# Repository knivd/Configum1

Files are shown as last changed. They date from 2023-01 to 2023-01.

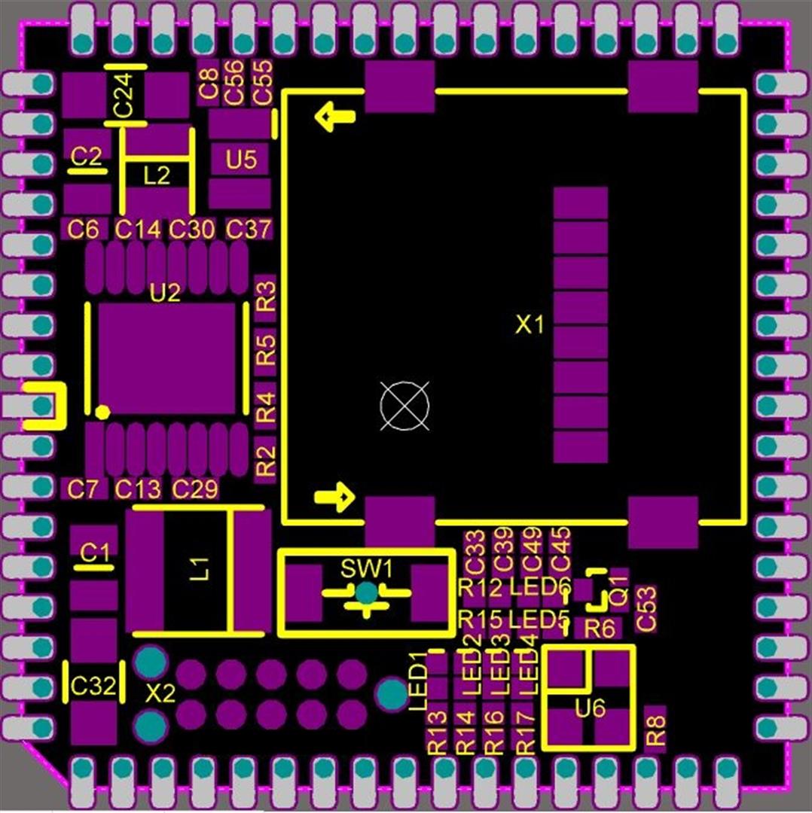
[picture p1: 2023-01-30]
manufacturing/Assembly-TOP.JPG

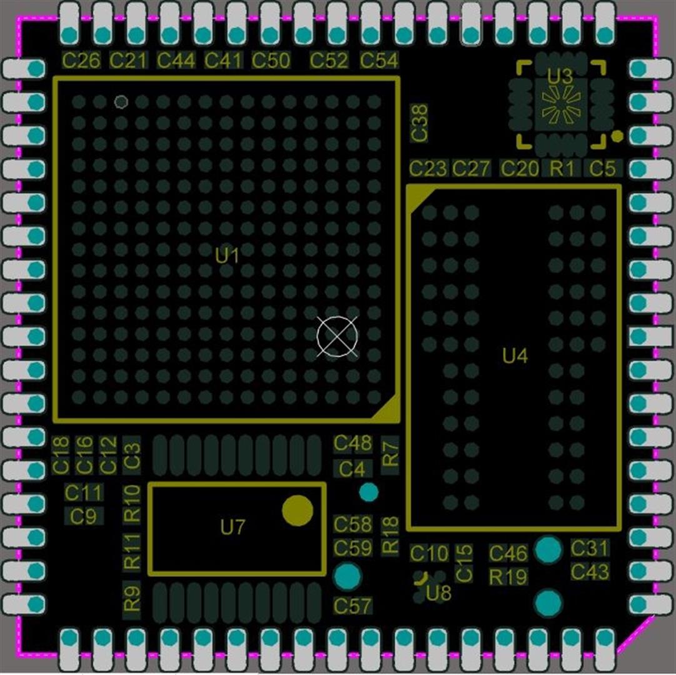
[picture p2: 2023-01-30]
manufacturing/Assembly-BOTTOM.JPG

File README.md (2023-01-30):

# Configum1
Embedded FPGA module in PLCC68 format

This tiny module has Spartan-6 FPGA, full power for it (works from any power outside in the range 3.3...20V, and even generates 3.3V for external user circuits), configuration memory, 64Mbytes DDR, microSD holder, 24MHz clock oscillator, JTAG pads, reset button, 8-bit configurable universal ADC/DAC/IO port, and even four on-board user-controllable LEDs.

And this whole this is... only 25x25mm big and fits into a standard PLCC-68 socket.

Applications - everything from industrial control to soft-core modular computers.

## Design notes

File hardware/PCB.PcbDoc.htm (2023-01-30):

Reporting Options

# File in Previous Format

Date | : | 23/02/2017
Time | : | 21:50:20
Filename | : | K:\Work\Orphidia\Projects\Others\Configum\hardware\PCB.PcbDoc

Version | Warning

This file was generated by an earlier version of the software

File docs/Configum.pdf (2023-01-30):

# CONFIGUM

24950C

# Embedded FPGA Module

## DTX bus compatible

# DATA SHEET

## 1. Overview

### Feature Highlights

68-pin device in standard PLCC68 package; three possible ways of PCB mounting
DTX bus pin-compatible (3.3V logic levels)
Wide range input 5-20V DC power supply with capability of provision to external circuit Fully self-contained – does not need any external components to run
Xilinx Spartan-6® FPGA with 14579 logic cells (CSG225 package)
Xilinx configuration memory with JTAG support
64 Megabytes DDR memory
micro-SD card connector on board
24MHz crystal oscillator
Four built-in controllable LEDs
Up to 45 FPGA I/O lines plus 8-bit dedicated ADC/DAC/IO front-end Tag-Connect®

pads and reset button
RoHS compliant

### Typical Applications

- Soft-core computing
- Robotics
- High-speed data processing
- Hobby and academic projects
24950C | 1 / 6

## 2. Pinout

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
┌─┴─┴─┴─┴─┴─┴─┴─┴─┸─┴─┴─┴─┴─┴─┴─┴─┴─┐
│ 9 │ 7 │ 5 │ 3 │ ▲ 68│ 66│ 64│ 6261│
+VBAT ┤10 8 | 6 | 4 | 2 1 | 67 65 63 60├ F0
GND ┤11 | | | | 59├ F1
+3V3OUT ┤12 | | | | 58├ F2
nRESET ┤13 | | | | 57├ F3
F44 ┤14 | | | | 56├ F4
F43 ┤15 | | | | 55├ F5
F42 ┤16 | | | | 54├ F6
F41 ┤17 | | | | 53├ F7
F40 ┤18 | | | | 52├ F8
F39 ┤19 | | | | 51├ F9
F38 ┤20 | | | | 50├ F10
F37 ┤21 | | | | 49├ F11
F36 ┤22 | | | | 48├ F12
F35 ┤23 | | | | 47├ F13
F34 ┤24 | | | | 46├ F14
F33 ┤25 | | | | 45├ F15
F32 ┤26 28 30 32 34 36 38 40 4244├ F16 │ 27│ 29│ 31│ 33│ 35│ 37│ 39│ 41│ 43│ └─┬─┬─┬─┬─┬─┬─┬─┬─┬─┬─┬─┬─┬─┬─┬─┬─┬─┘

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
### Pinout Summary

Pin | Name | Type | Description
1 | GND | P | Ground
2 | TMS | I | JTAG TMS line
3 | TCK | I | JTAG TCK line
4 | TDO | O | JTAG TDO line
5 | TDI | I | JTAG TDI line
6 | INIT | I | FPGA INIT input; delays initialisation
7 | GND | P | Ground
8 | +VBAT | P | Positive power lead

9 | PWRON | I | Power enabling input (can be connected directly to +VBAT); active high
10 | +VBAT | P | Positive power lead
11 | GND | P | Ground
12 | +3V3OUT | P | +3.3V output from the internal regulator; can be used to supply power to external components and circuits
13 | nRESET | I | RESET line; internally biased to +3.3V
14 | F44 | I,O | FPGA pin B15
15 | F43 | I,O | FPGA pin H12
16 | F42 | I,O | FPGA pin F11
17 | F41 | I,O | FPGA pin G12
18 | F40 | I,O | FPGA pin F12
19 | F39 | I,O | FPGA pin G13
20 | F38 | I,O | FPGA pin F13
21 | F37 | I,O | FPGA pin H13
22 | F36 | I,O | FPGA pin G14
23 | F35 | I,O | FPGA pin E14
24 | F34 | I,O | FPGA pin B14
25 | F33 | I,O | FPGA pin C14
26 | F32 | I,O | FPGA pin H15
27 | FX | I,O | FPGA pin J14
28 | GND | P | Ground
29 | F31 | I,O | FPGA pin J13
30 | F30 | I,O | FPGA pin K13
31 | F29 | I,O | FPGA pin K12
32 | F28 | I,O | FPGA pin D15
33 | F27 | I,O | FPGA pin E15
34 | F26 | I,O | FPGA pin G15
35 | F25 | I,O | FPGA pin J15
36 | F24 | I,O | FPGA pin K15
37 | F23 | I,O | FPGA pin L14
38 | F22 | I,O | FPGA pin L15
39 | F21 | I,O | FPGA pin L12
40 | F20 | I,O | FPGA pin M15
41 | F19 | I,O | FPGA pin M13
42 | F18 | I,O | FPGA pin N15
43 | F17 | I,O | FPGA pin N14
44 | F16 | I,O | FPGA pin P15

45 | F15 | I,O | FPGA pin P14
46 | F14 | I,O | FPGA pin K11
47 | F13 | I,O | FPGA pin J11
48 | F12 | I,O | FPGA pin G11
49 | F11 | I,O | FPGA pin R11
50 | F10 | I,O | FPGA pin R10
51 | F9 | I,O | FPGA pin R9
52 | F8 | I,O | FPGA pin R8
53 | F7 | I,O | FPGA pin R6
54 | F6 | I,O | FPGA pin R5
55 | F5 | I,O | FPGA pin R4
56 | F4 | I,O | FPGA pin R13
57 | F3 | I,O | FPGA pin P13
58 | F2 | I,O | FPGA pin R7
59 | F1 | I,O | FPGA pin N11
60 | F0 | I,O | FPGA pin M11
61 | P0 | I,O,AI,AO | Universal front-end line 0
62 | P1 | I,O,AI,AO | Universal front-end line 1
63 | P2 | I,O,AI,AO | Universal front-end line 2
64 | P3 | I,O,AI,AO | Universal front-end line 3
65 | P4 | I,O,AI,AO | Universal front-end line 4
66 | P5 | I,O,AI,AO | Universal front-end line 5
67 | P6 | I,O,AI,AO | Universal front-end line 6
68 | P7 | I,O,AI,AO | Universal front-end line 7

Legend:
I – input with CMOS level | O – digital output | P – power pin
AI – analogue input | AO – analogue output

## 3. Electrical Parameters

ABSOLUTE MAXIMUM RATINGS:
Stresses beyond those listed under "absolute maximum ratings" may cause permanent damage to the device. These are stress ratings only, and functional operation of the device at these or any other conditions beyond those indicated under "recommended operating conditions" is not implied. Exposure to absolute-maximum-rated conditions for extended periods may affect device reliability.
parameter | min | typ | max | units
Power supply voltage range, pin +VBAT with respect to GND | 5 | 9 | 20 | V
Safe load on +3V3OUT pin | | | 250 | mA
Parameters of all other functional pins | According to function and IC manufacturer's recommendation
Operating free-air temperature range | -20 | | +85 | °C
Storage temperature range | -40 | | +90 | °C

## 4. Mechanical Parameters

Note: All dimensions are given in millimetres

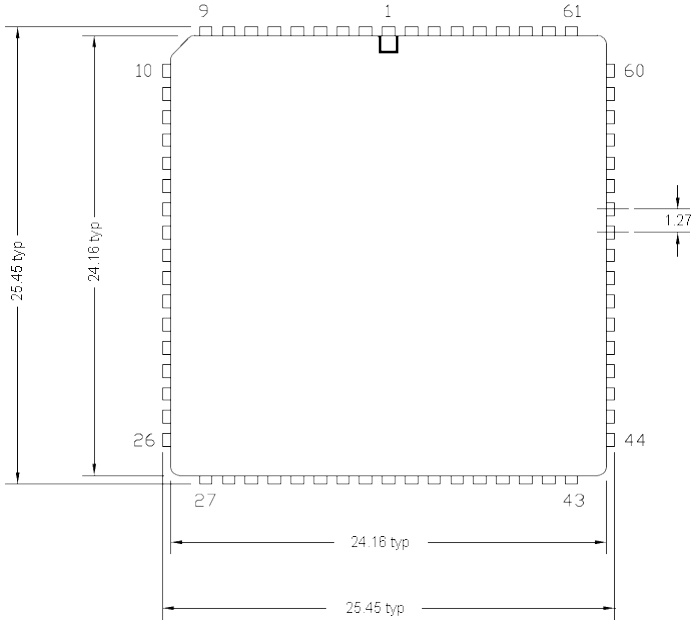
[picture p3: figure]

## 5. Internal Schematic

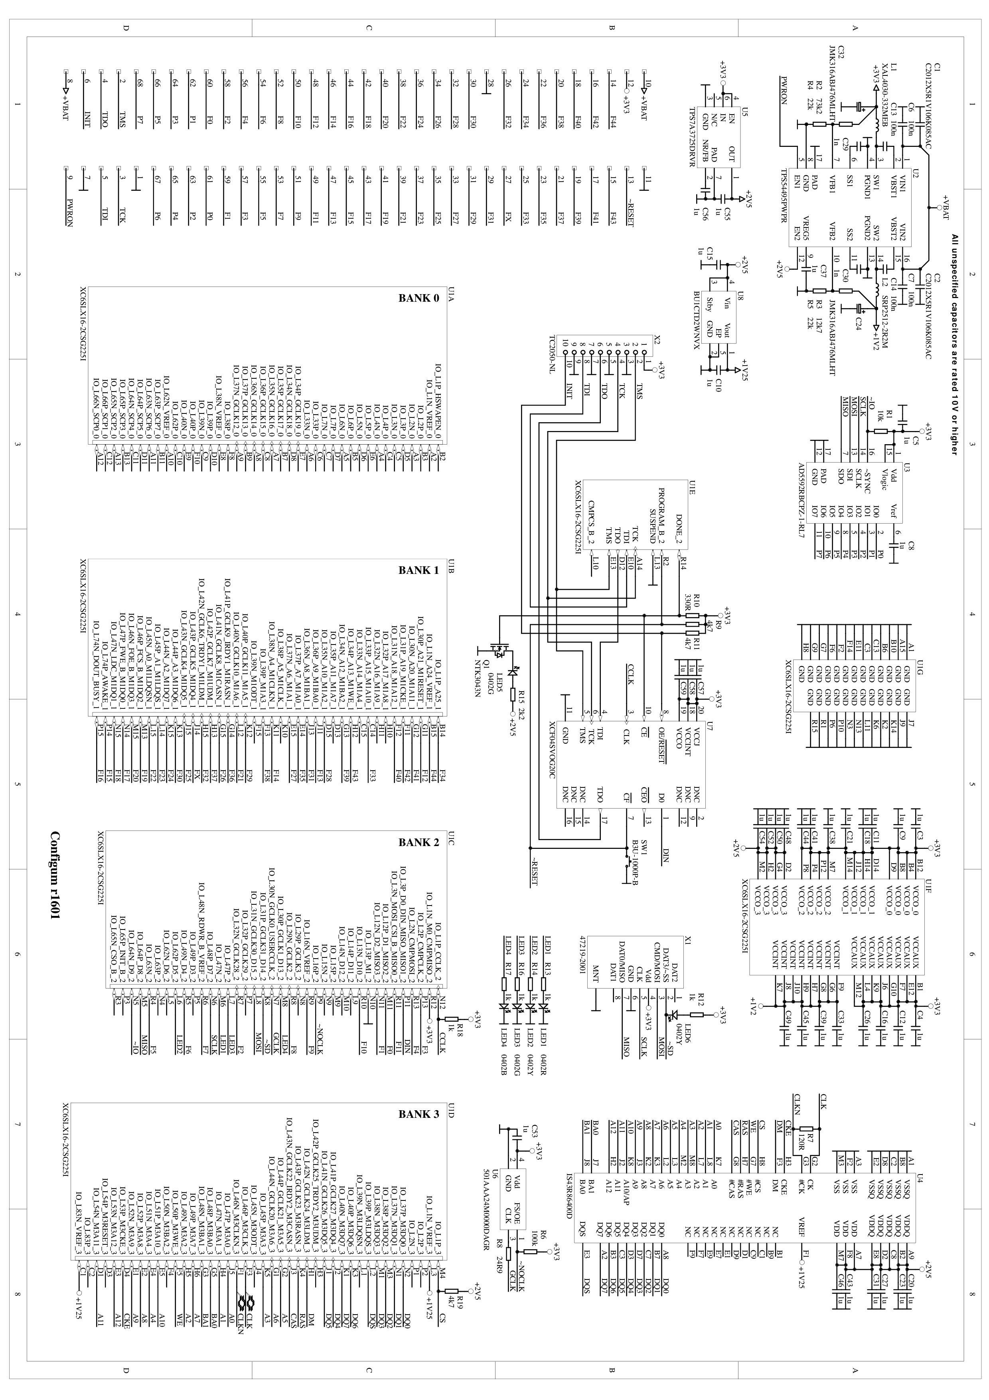
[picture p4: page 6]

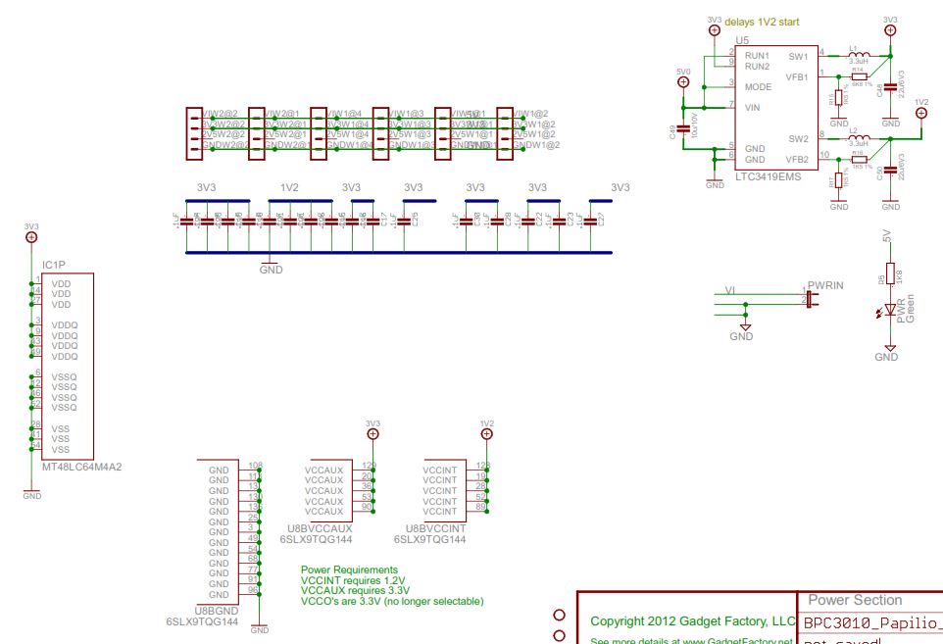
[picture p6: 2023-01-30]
docs/Spartan 6/Examples/Capture1.JPG

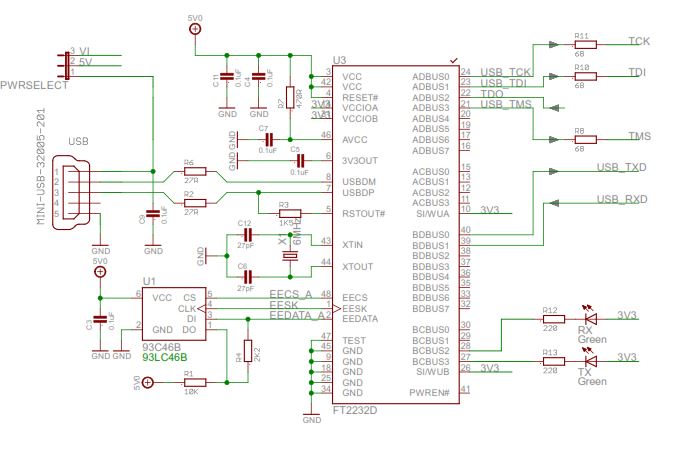
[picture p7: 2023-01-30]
docs/Spartan 6/Examples/Capture2.JPG

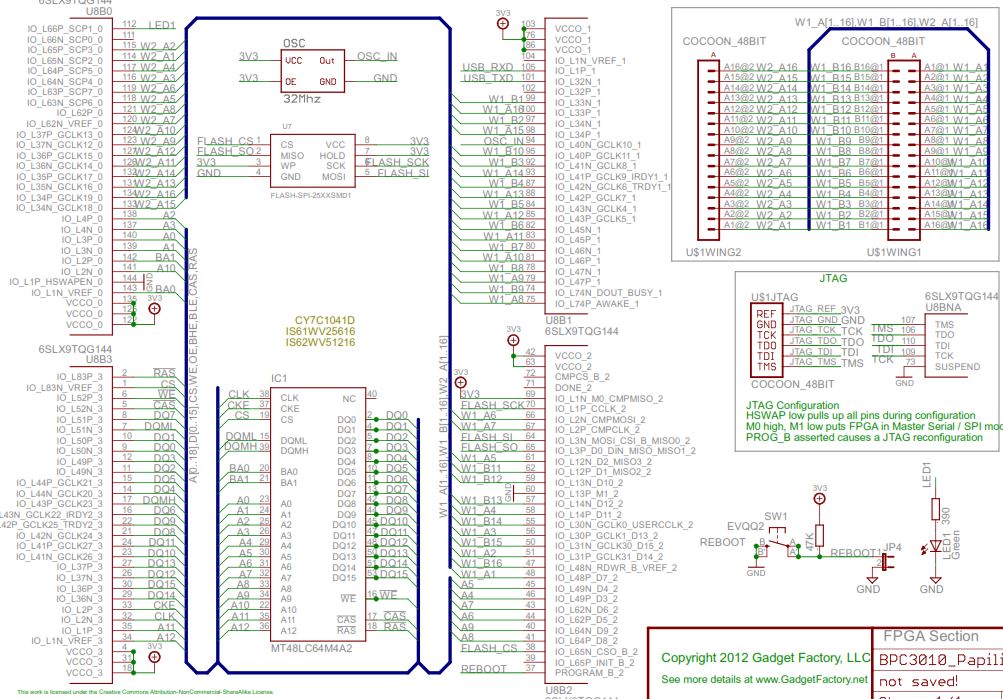
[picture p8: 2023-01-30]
docs/Spartan 6/Examples/Capture3.JPG

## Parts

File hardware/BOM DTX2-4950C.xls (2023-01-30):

Comment | Pattern | Quantity | Components | Vendor | Order Code | Vendor | Order Code | Description
C2012X5R1V106K085AC | _0805 | 2 | C1, C2 | Mouser | 810-C2012X5R1V106K0C | Digikey | 445-14417-1-ND | Capacitor
JMK316ABJ476MLHT | _1206 | 2 | C24, C32 | Mouser | 963-JMK316ABJ476MLHT | Digikey | 587-3399-1-ND | Polar capacitor
1n | _0402 | 2 | C29, C30 | Mouser | 77-VJ0402Y102JXACBC | Digikey | 399-10034-1-ND | Capacitor
1u | _0402 | 37 | C3, C4, C5, C8, C9, C10, C11, C12, C15, C16, C18, C20, C21, C23, C26, C27, C31, C33, C37, C38, C39, C41, C43, C44, C45, C46, C48, C49, C50, C52, C53, C54, C55, C56, C57, C58, C59 | Mouser | 810-CGB2A1X7S0J105BC | Digikey | 490-9665-1-ND | Capacitor
100n | _0402 | 4 | C6, C7, C13, C14 | Mouser | 810-C1005X7R1H104K | Digikey | 445-5932-1-ND | Capacitor
XAL4030-332MEB | IND_4X4 | 1 | L1 | Mouser | 994-XAL4030-332MEB | Digikey |  | Inductor
SRP2512-2R2M | IND_2.5x2 | 1 | L2 | Mouser | 652-SRP2512-2R2M | Digikey | SRP2512-2R2MCT-ND | Inductor
0402R | _0402+ | 1 | LED1 | Mouser | 78-VLMS1500-GS08 | Digikey | 754-1104-1-ND | Light Emitting Diode
0402Y | _0402+ | 2 | LED2, LED6 | Mouser | 78-VLMY1500-GS08 | Digikey | 754-1105-1-ND | Light Emitting Diode
0402G | _0402+ | 2 | LED3, LED5 | Mouser | 78-VLMG1500-GS08 | Digikey | 754-1101-1-ND | Light Emitting Diode
0402B | _0402+ | 1 | LED4 | Mouser | 78-VLMB1500-GS08 | Digikey | 754-1813-1-ND | Light Emitting Diode
NTK3043N | SC105-3 | 1 | Q1 | Mouser | 863-NTK3043NT1G | Digikey | NTK3043NT1GOSCT-ND | N-channel FET transistor
10k | _0402 | 1 | R1 | Mouser | 71-CRCW0402-10K-E3 | Digikey | 541-10.0KLCT-ND | Resistor
330R | _0402 | 1 | R10 | Mouser | 71-CRCW0402-330-E3 | Digikey | 41-330LCT-ND | Resistor
1k | _0402 | 6 | R12, R13, R14, R16, R17, R18 | Mouser | 71-CRCW0402-1.0K-E3 | Digikey | 541-1.00KLCT-ND | Resistor
2k2 | _0402 | 1 | R15 | Mouser | 71-CRCW0402-2.2K-E3 | Digikey | 541-2.20KLCT-ND | Resistor
73k2 | _0402 | 1 | R2 | Mouser | 71-CRCW0402-73.2K-E3 | Digikey | 541-73.2KLCT-ND | Resistor
12k7 | _0402 | 1 | R3 | Mouser | 71-CRCW0402-12.7K-E3 | Digikey | 541-12.7KLCT-ND | Resistor
22k | _0402 | 2 | R4, R5 | Mouser | 71-CRCW0402-22K-E3 | Digikey | 541-22.0KLCT-ND | Resistor
100k | _0402 | 1 | R6 | Mouser | 71-CRCW0402-100K-E3 | Digikey | 541-100KLCT-ND | Resistor
120R | _0402 | 1 | R7 | Mouser | 71-CRCW0402120RFKED | Digikey | 541-120LCT-ND | Resistor
24R9 | _0402 | 1 | R8 | Mouser | 71-CRCW0402-24.9-E3 | Digikey | 541-24.9LCT-ND | Resistor
4k7 | _0402 | 3 | R9, R11, R19 | Mouser | 71-CRCW0402-4.7K-E3 | Digikey | 541-4.70KLCT-ND | Resistor
B3U-1000P-B | B3U-1000P-B | 1 | SW1 | Mouser | 653-B3U-1000P-B | Digikey | SW1143CT-ND | Switch, Momentary, Normal Open, SPST
XC6SLX16-2CSG225I | CSG225 | 1 | U1 | Mouser |  | Digikey | 122-1670-ND | Spartan-6 LX 1.2V FPGA, 160 User I/Os, 225-Ball Chip-Scale BGA (0.8mm Pitch), Speed Grade 2, Industrial Grade, Pb-Free
TPS54495PWPR | TSOP65P650X110_HS-16N | 1 | U2 | Mouser | 595-TPS54495PWPR | Digikey | 296-30583-1-ND | 4A/2A Dual Channel Synchronous Step-Down Switcher with Integrated FET
AD5592RBCPZ-1-RL7 | QFN50P300X300-16V4N | 1 | U3 | Mouser |  | Digikey |  | 8-Channel, 12-Bit, Configurable ADC/DAC with On-Chip Reference, SPI Interface
IS43R86400D | BGA60C80P12X9_1300X800X120 | 1 | U4 | Mouser | 870-IS43R86400D-5BL | Digikey |  | 64Mx8 DDR SDRAM
TPS7A3725DRVR | SON65P200x200_HS-6N | 1 | U5 | Mouser | 595-TPS7A3725DRVT | Digikey |  | 1% High-Accuracy, 1-A, Low-Dropout Regulator with Reverse Current Protection
501AAA24M0000DAGR | Osc 25x20 (4) | 1 | U6 | Mouser | 634-01AAA24M0000DAGR | Digikey | 336-2915-ND | 32kHz –100MHz CMEMS Oscillator
XCF04SVOG20C | VOG20_L | 1 | U7 | Mouser |  | Digikey | 122-1288-5-ND | XCF00S Series, Platform Flash In-System Programmable Configuration 3.3V PROM, 20-Pin TSOP, 4-Megabit, Commercial Grade, Pb-Free
BU1CTD2WNVX | DFN65P100x100-4 | 1 | U8 | Mouser | 755-BU1CTD2WNVX-TL | Digikey | BU1CTD2WNVX-TLCT-ND | 1.25V 200mA LDO in 1mm x 1mm package
47219-2001 | MOLEX_47219-2001 | 1 | X1 | Mouser | 538-47219-2001 | Digikey | WM6698CT-ND | microSD card connector

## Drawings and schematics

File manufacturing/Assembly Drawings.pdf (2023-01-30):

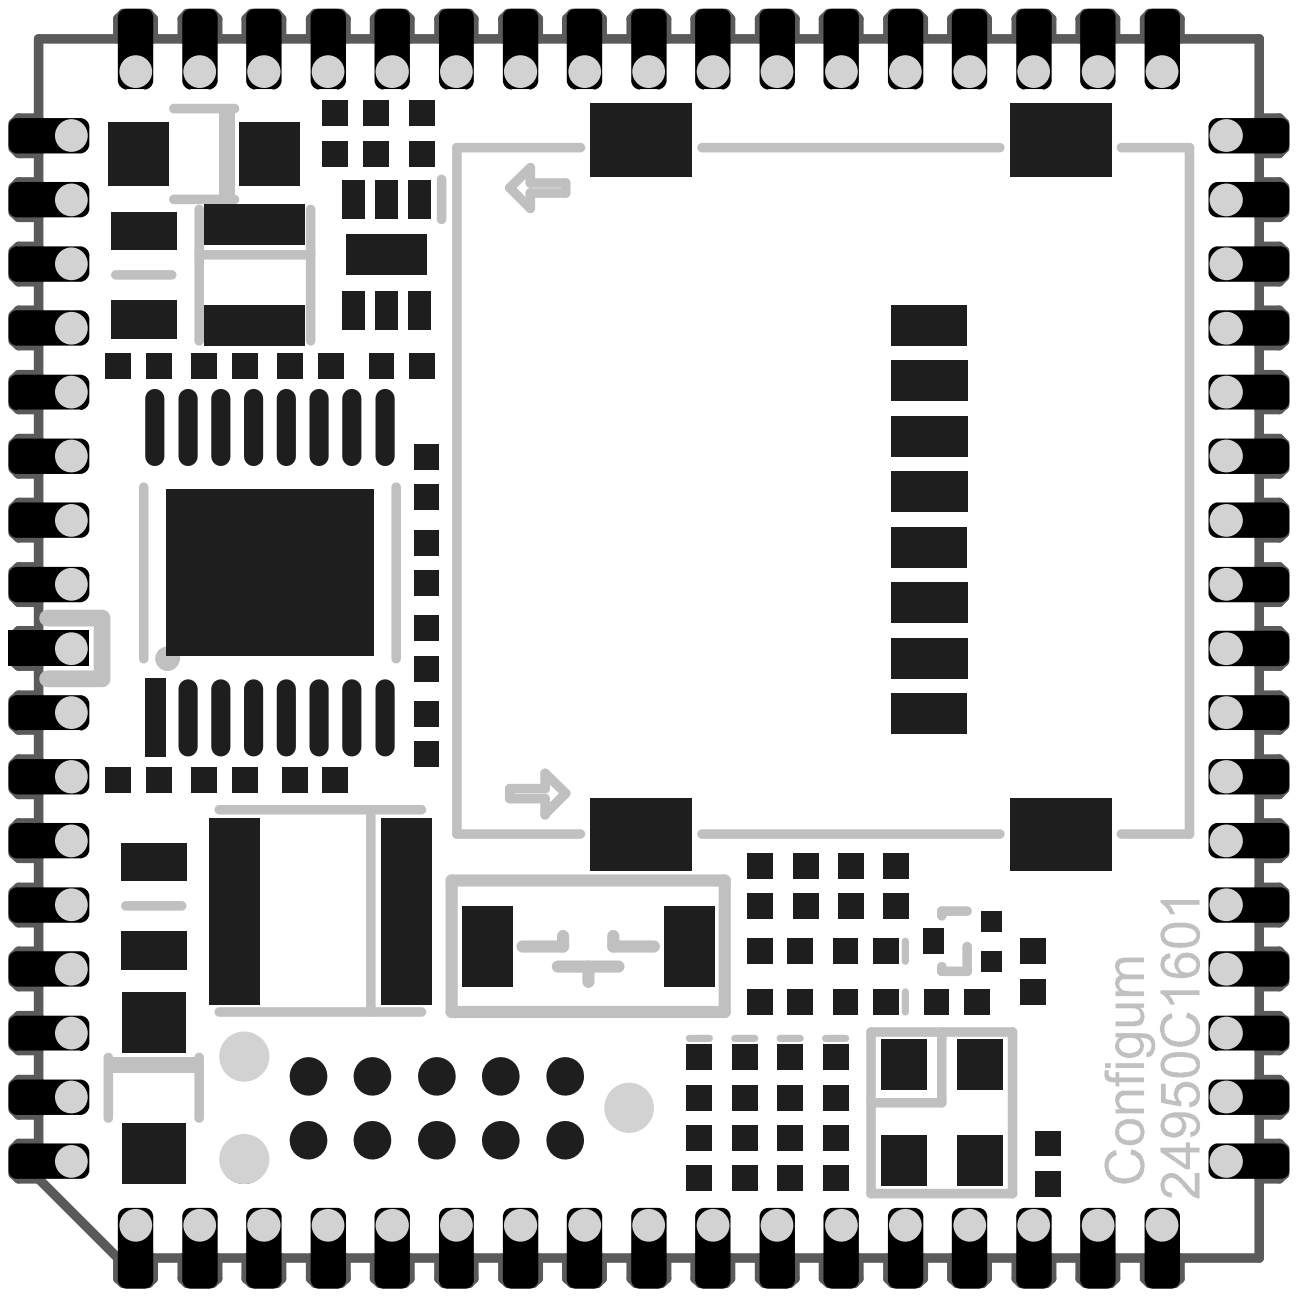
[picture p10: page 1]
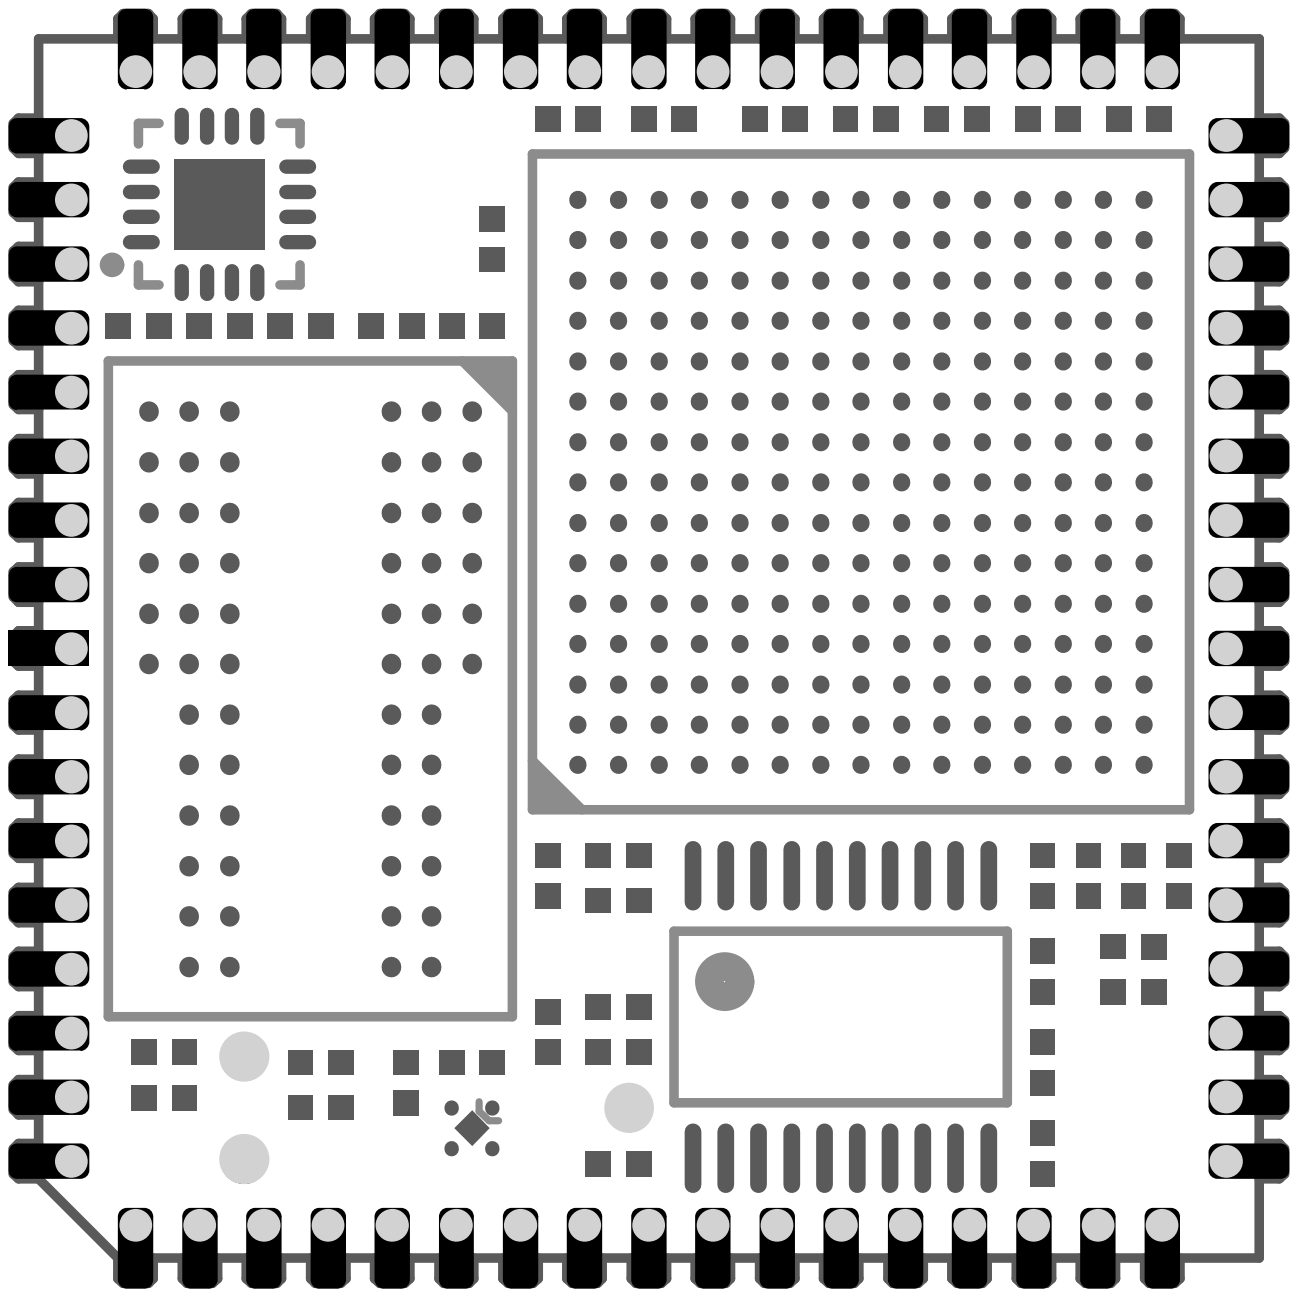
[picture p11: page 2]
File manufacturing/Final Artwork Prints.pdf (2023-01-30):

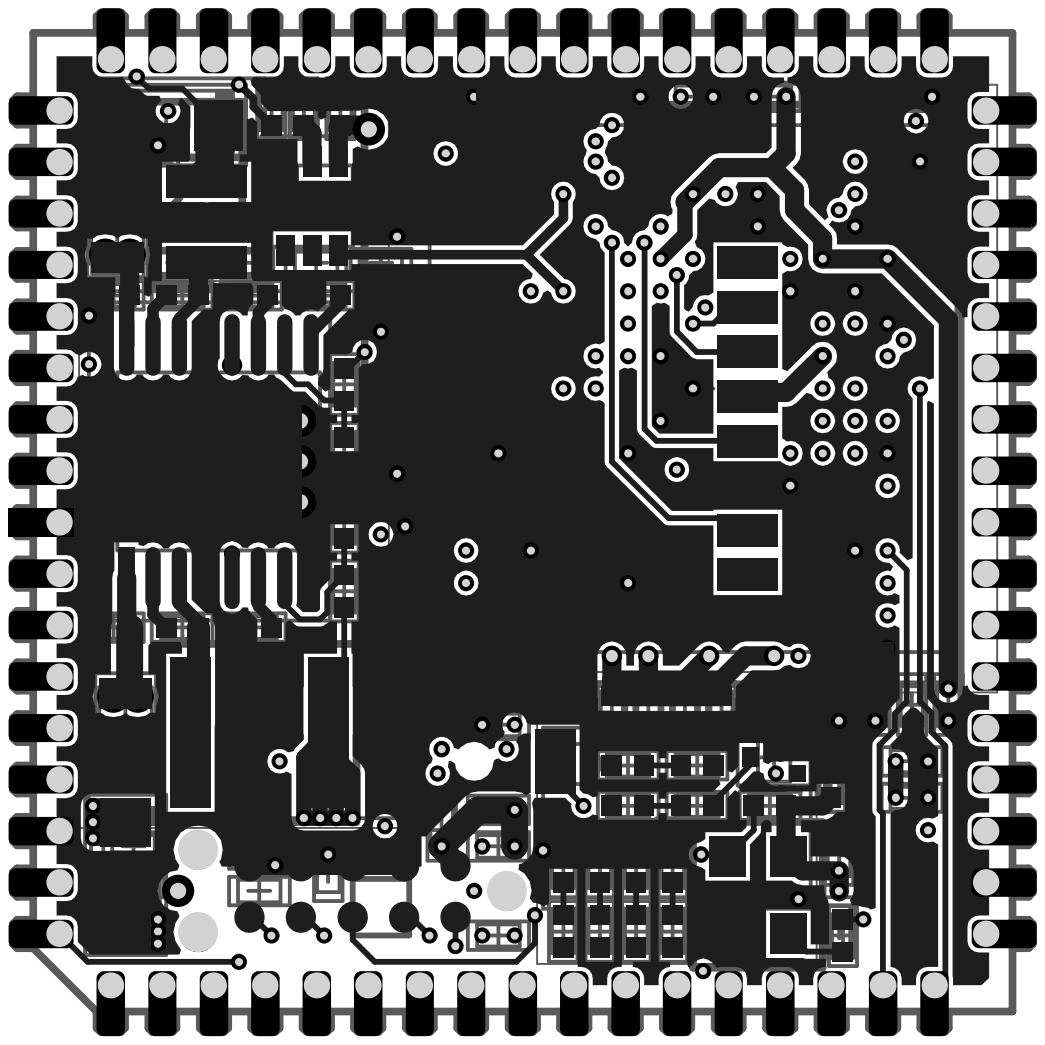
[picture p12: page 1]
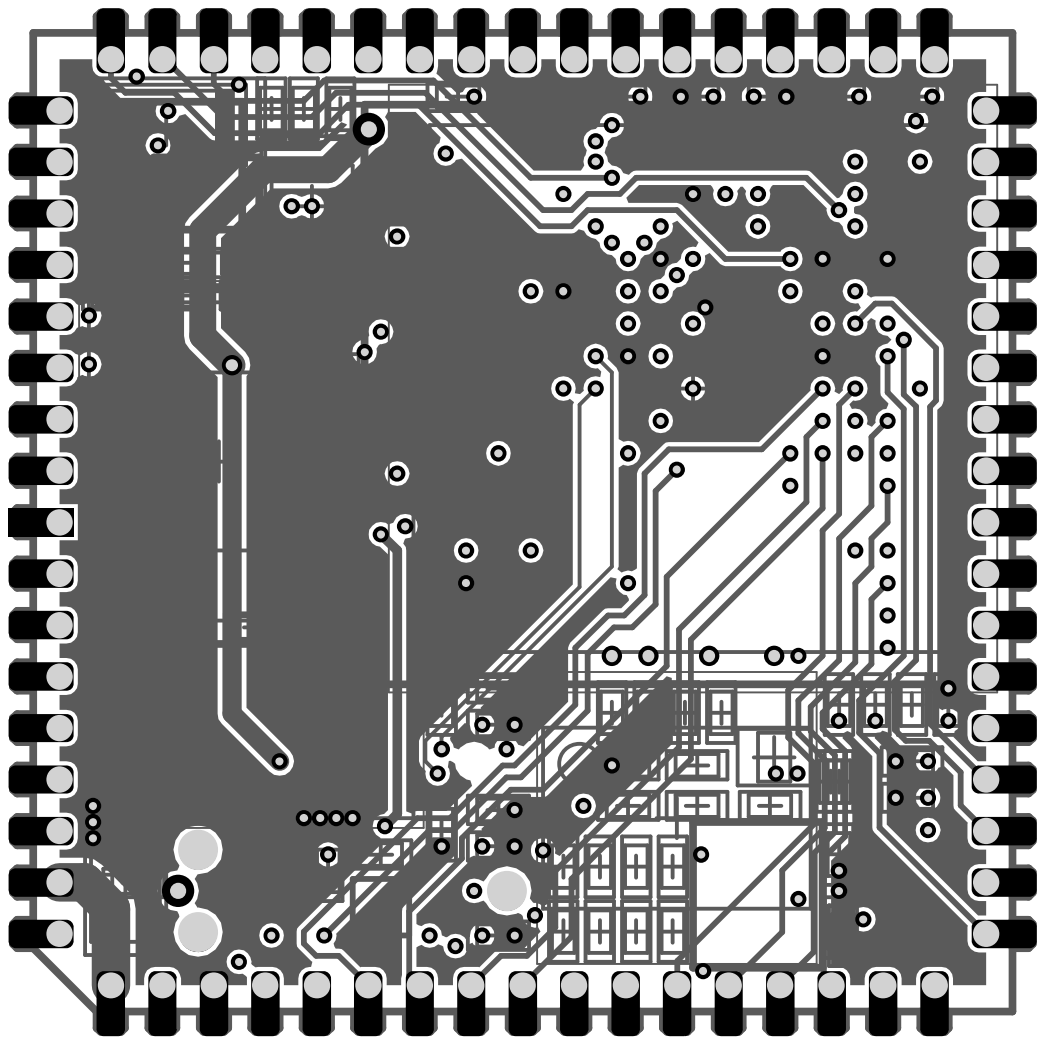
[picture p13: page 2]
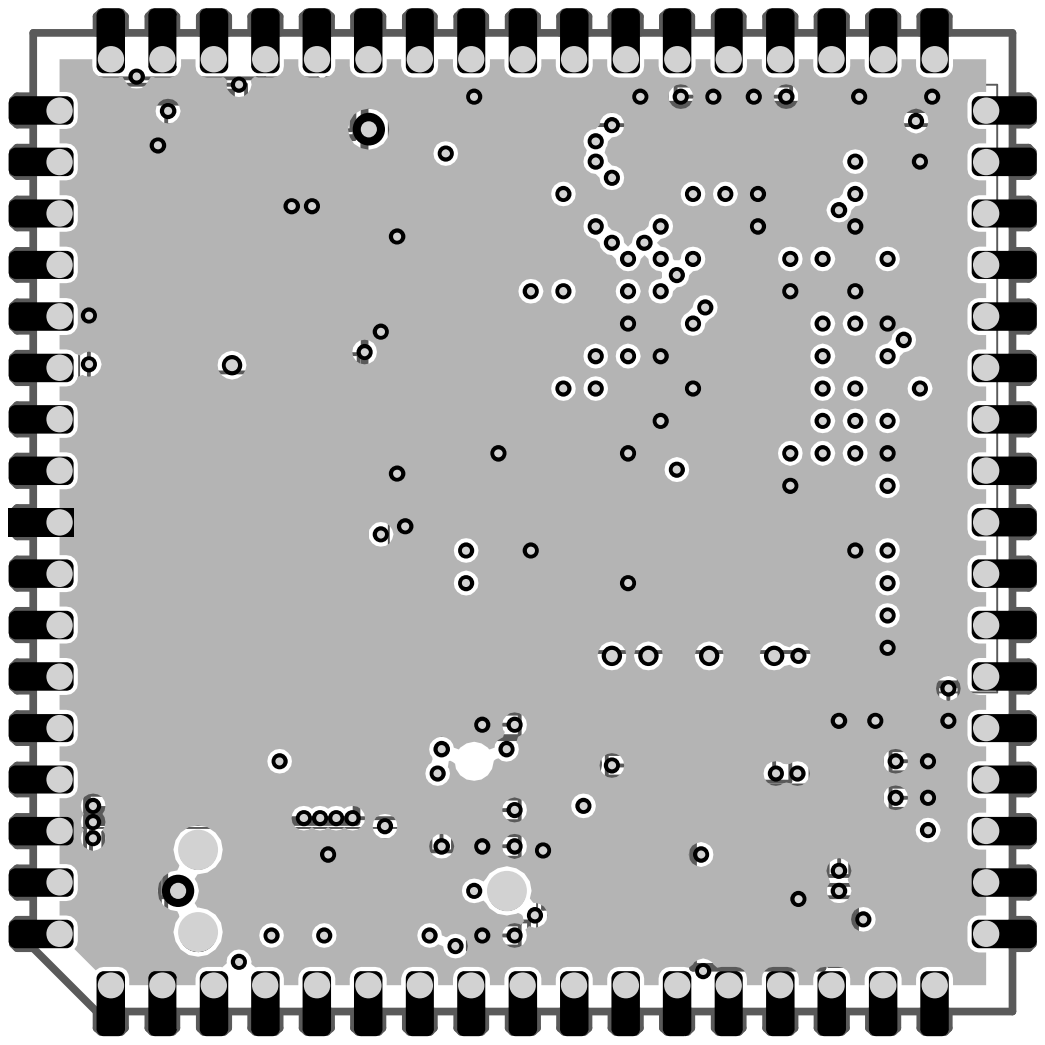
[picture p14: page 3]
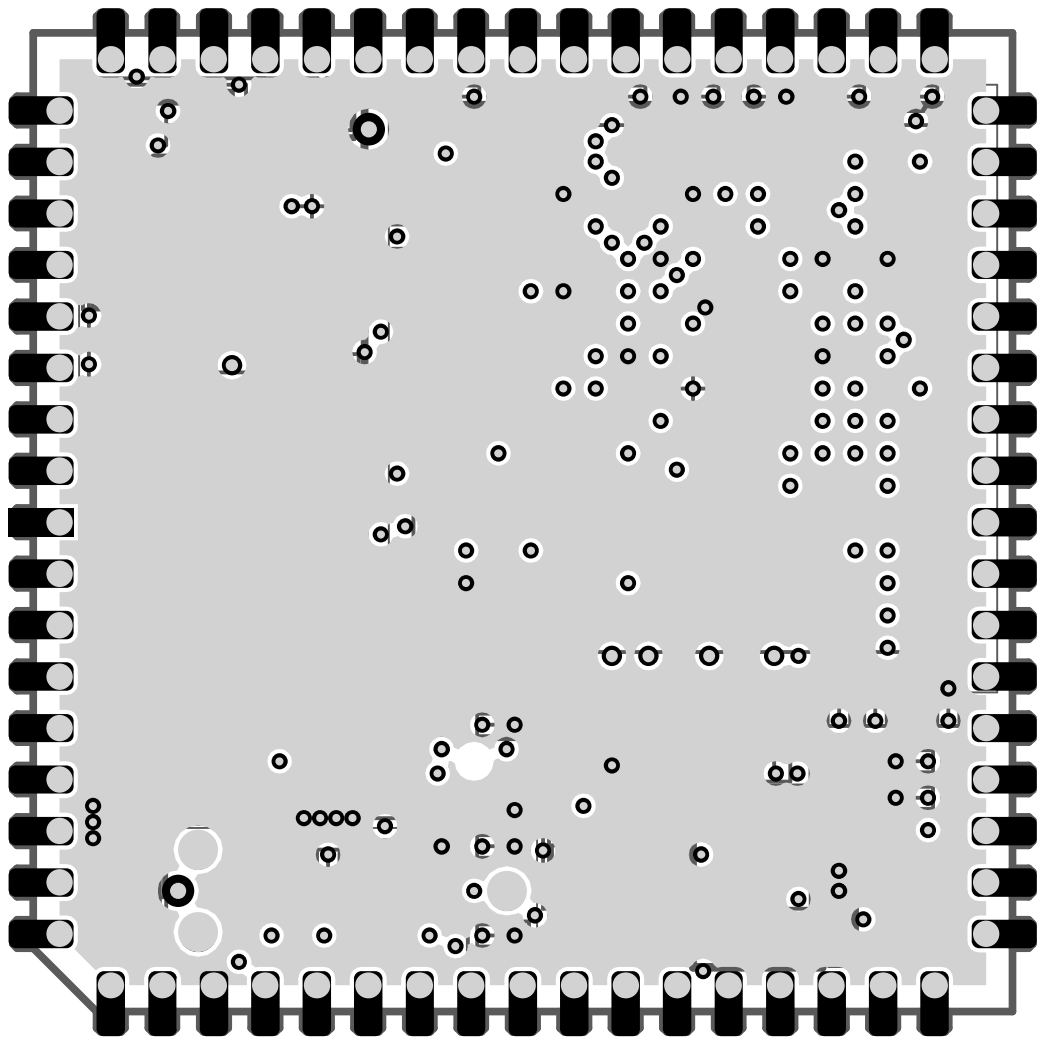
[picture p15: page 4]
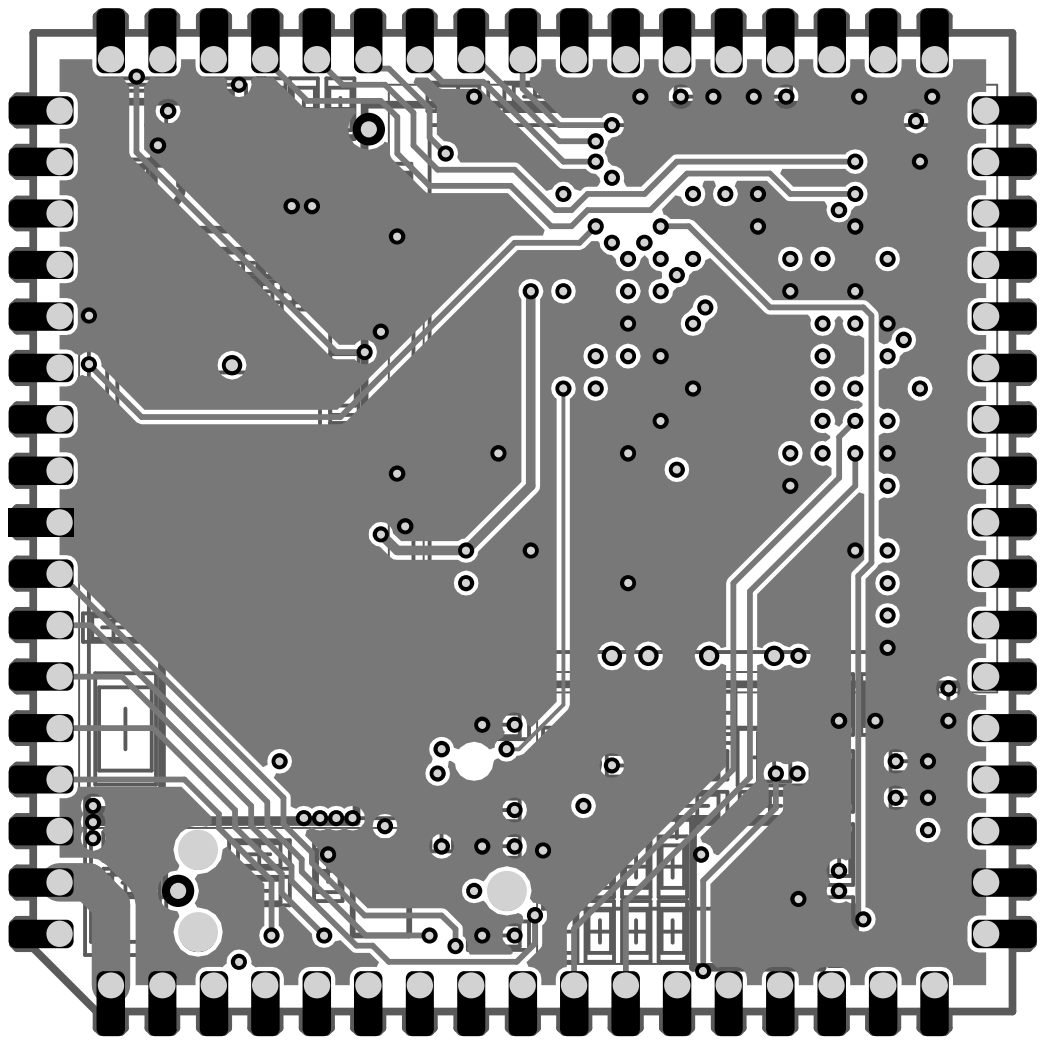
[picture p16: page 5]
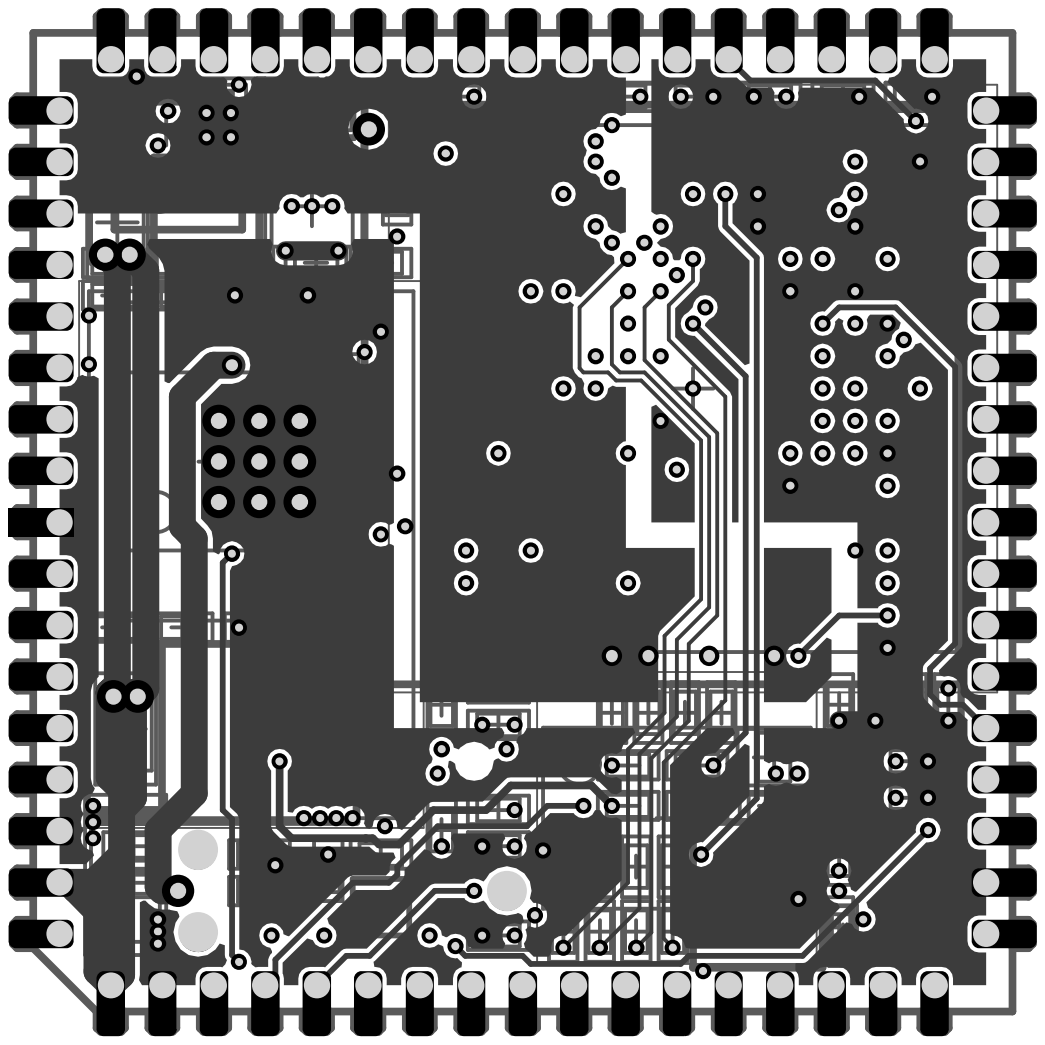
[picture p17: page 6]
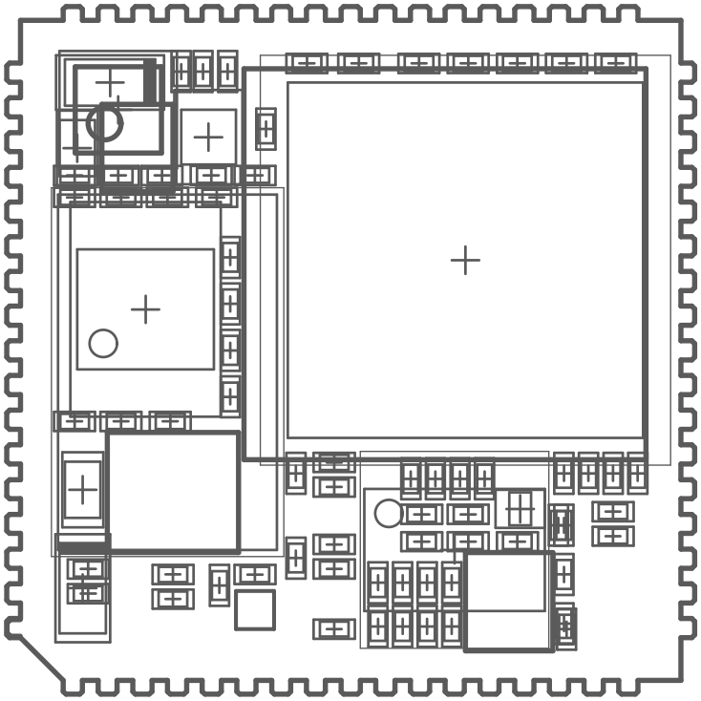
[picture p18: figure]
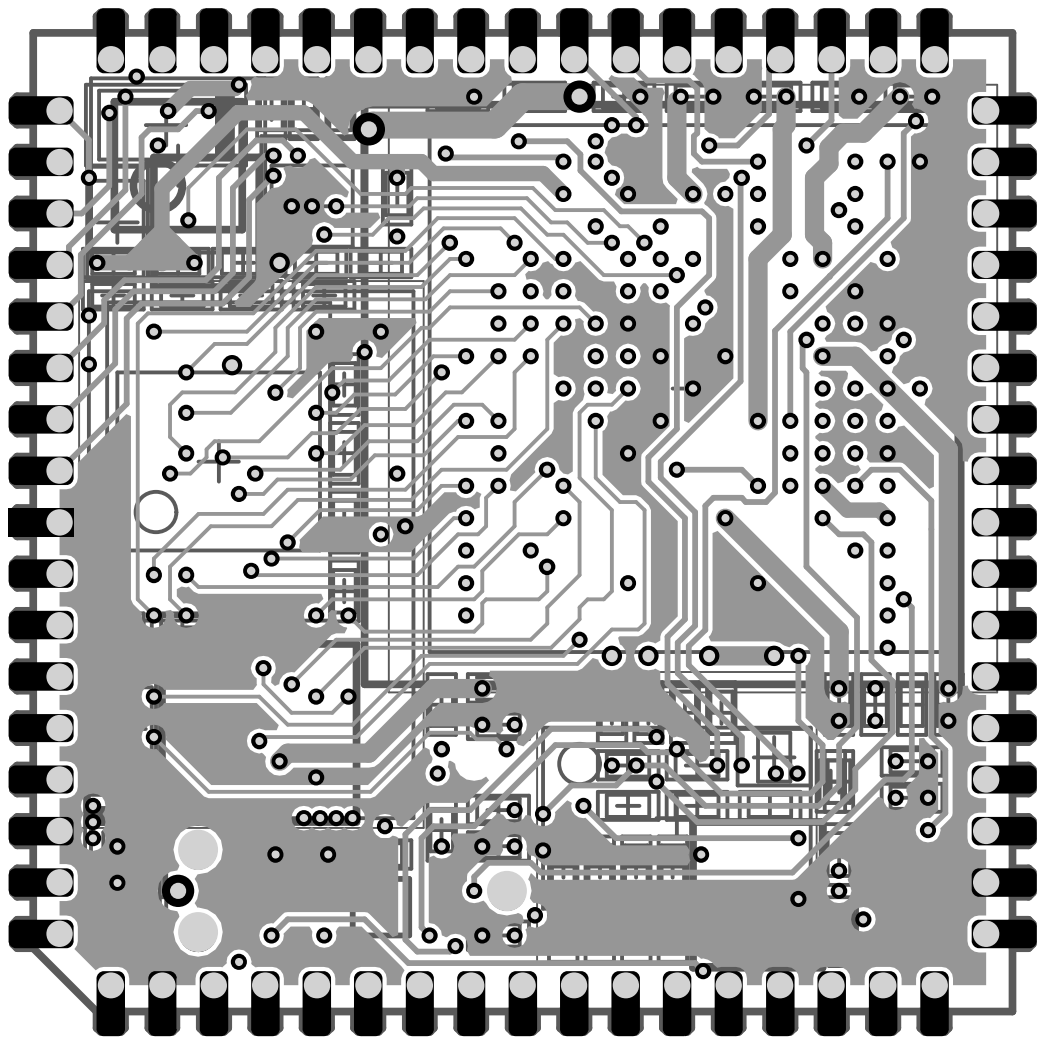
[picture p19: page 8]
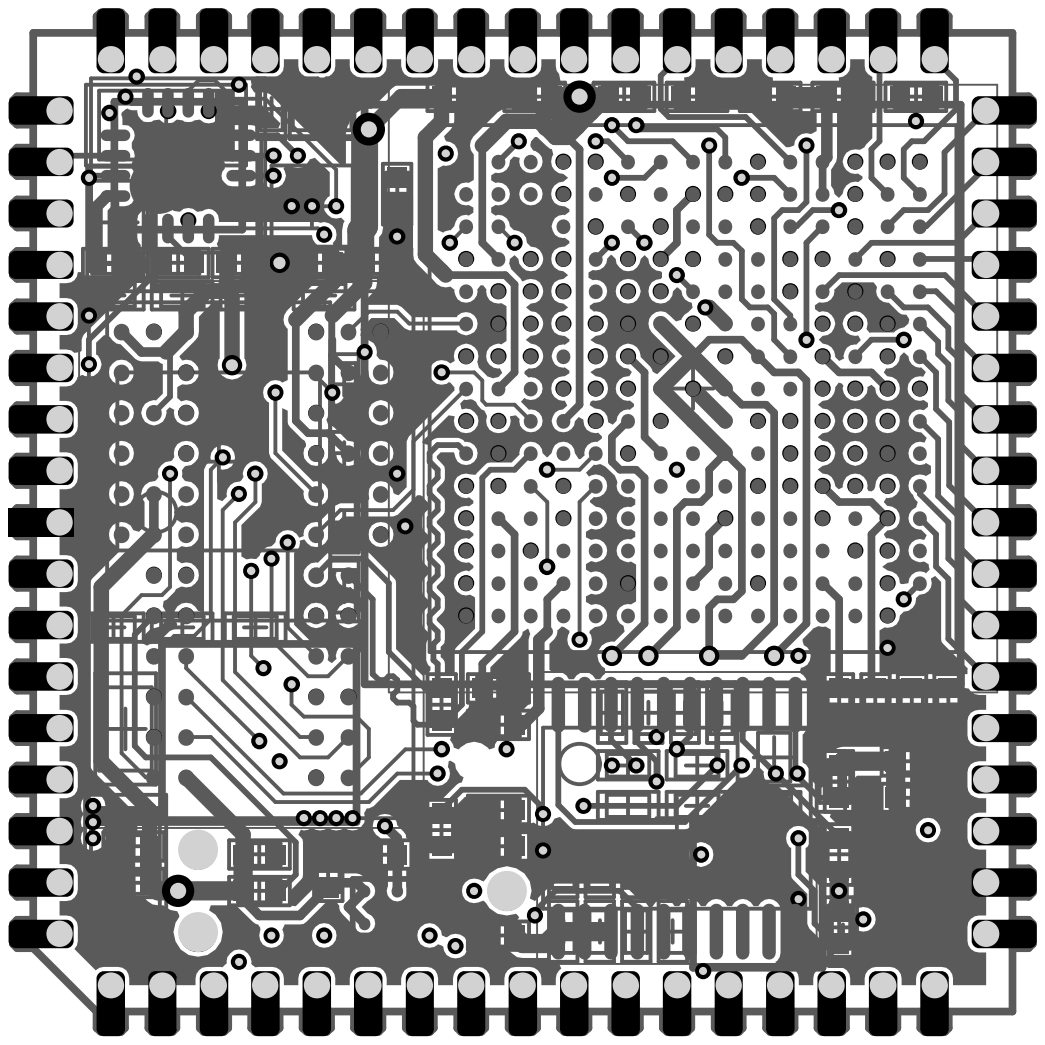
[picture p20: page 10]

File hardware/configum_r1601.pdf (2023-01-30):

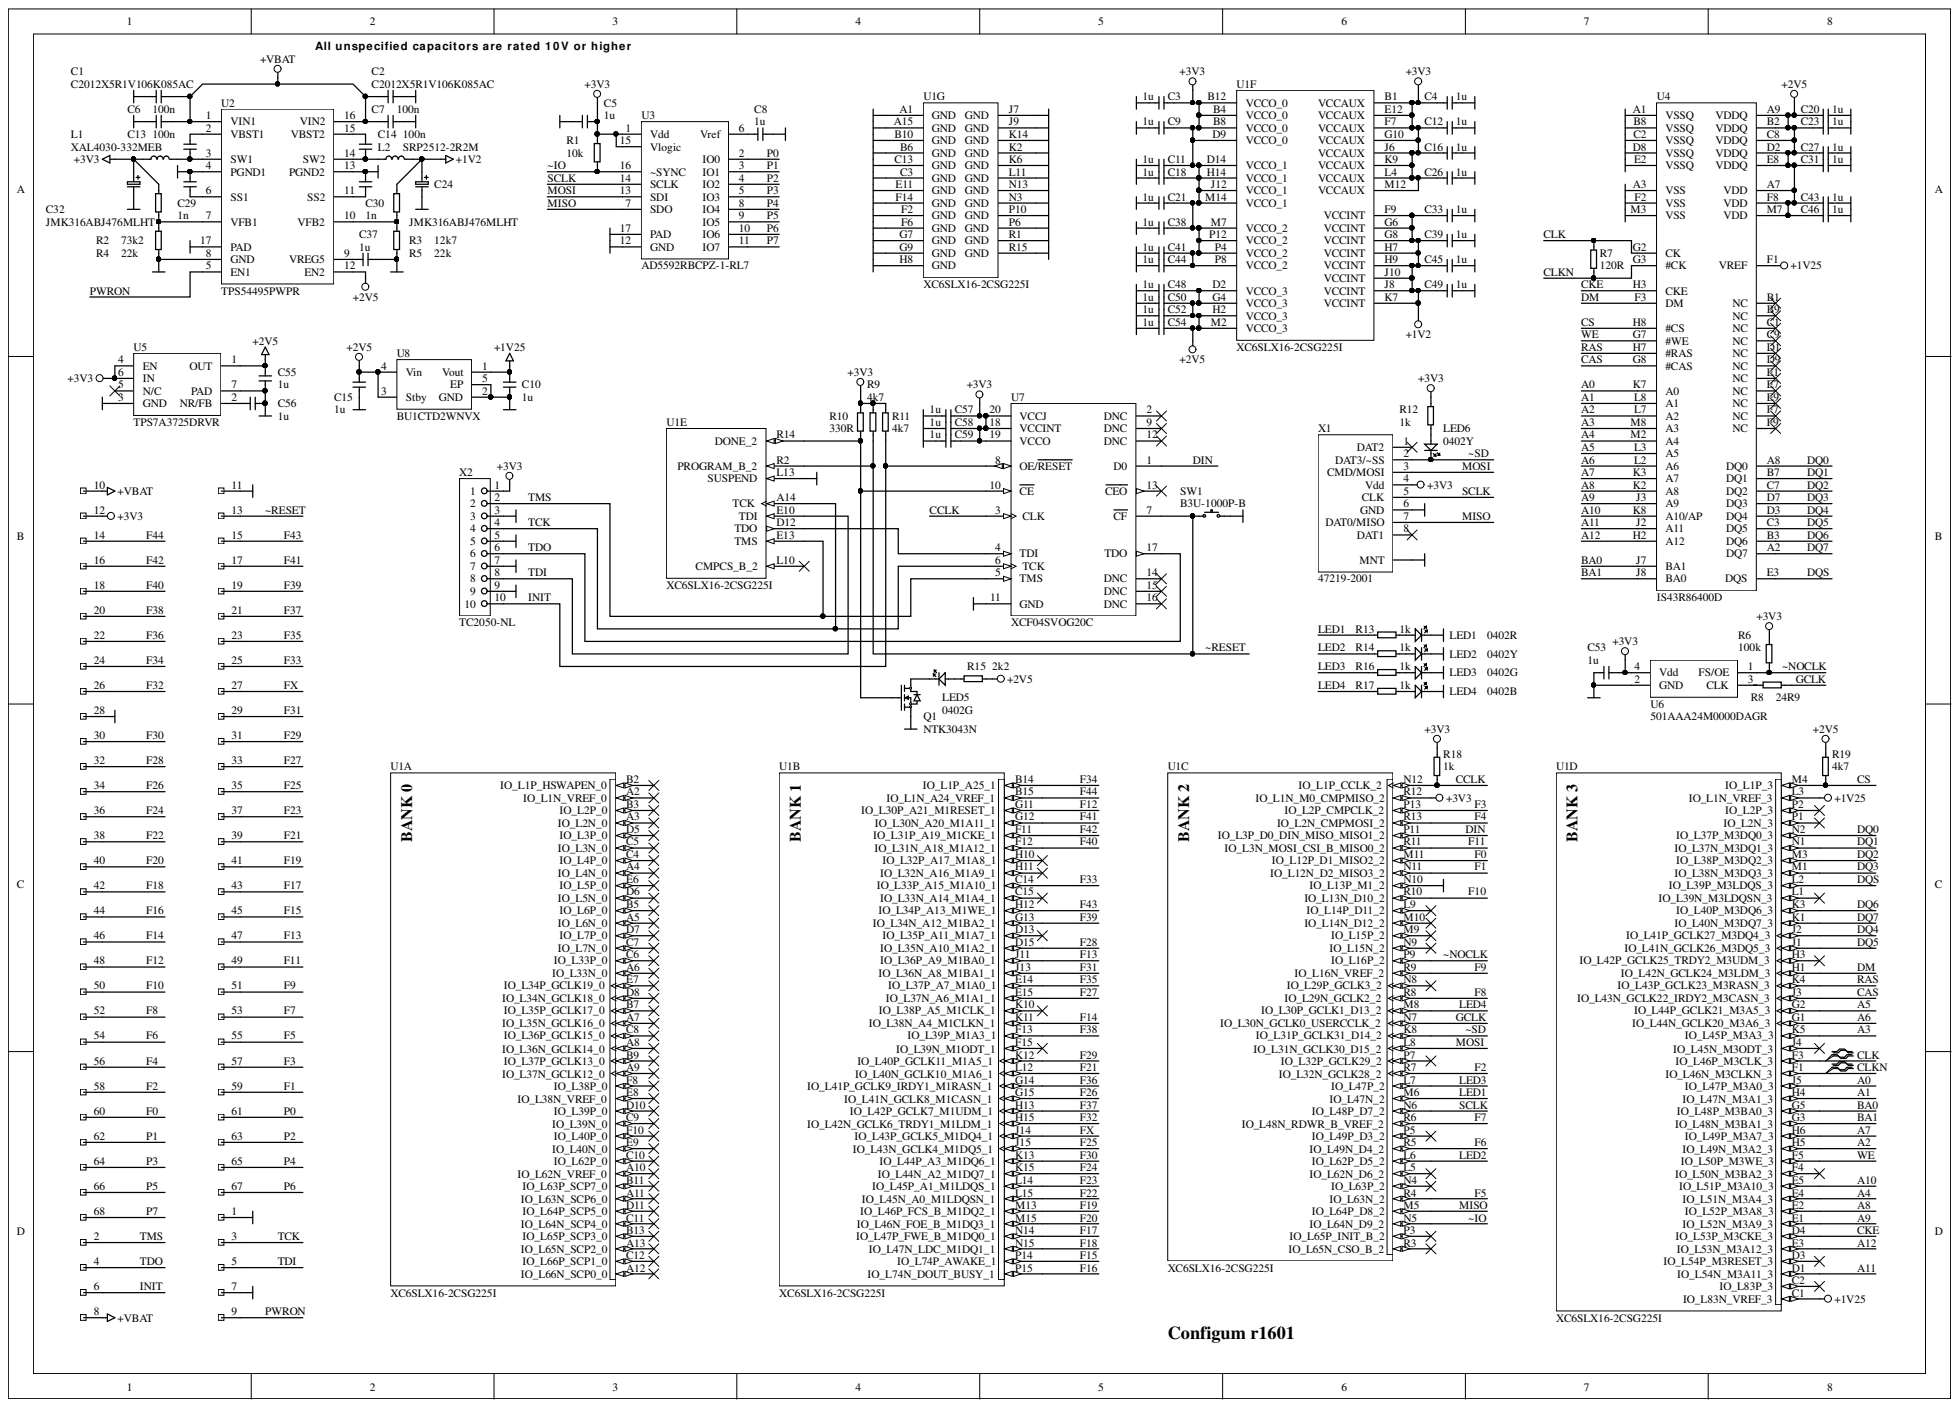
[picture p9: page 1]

All unspecified capacitors are rated 1 0 V or higher
